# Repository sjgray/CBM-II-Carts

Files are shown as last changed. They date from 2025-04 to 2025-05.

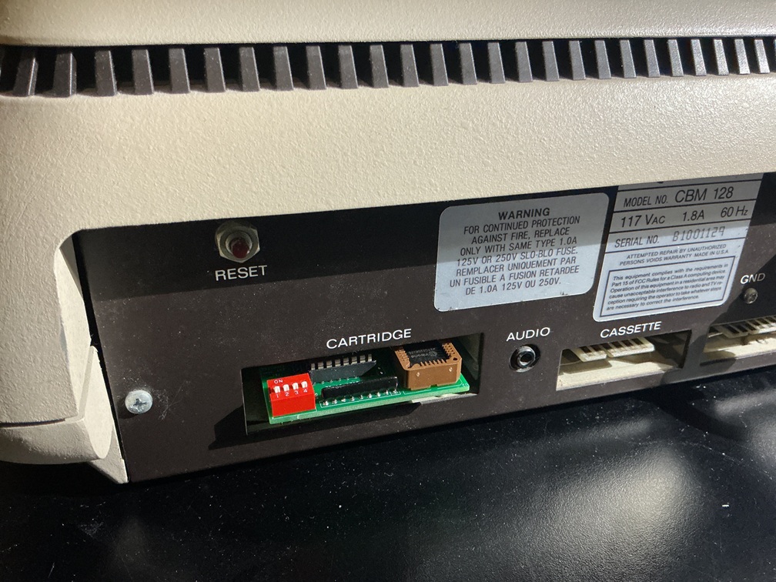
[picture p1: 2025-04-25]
ROMCart/_Pics/installed.jpg

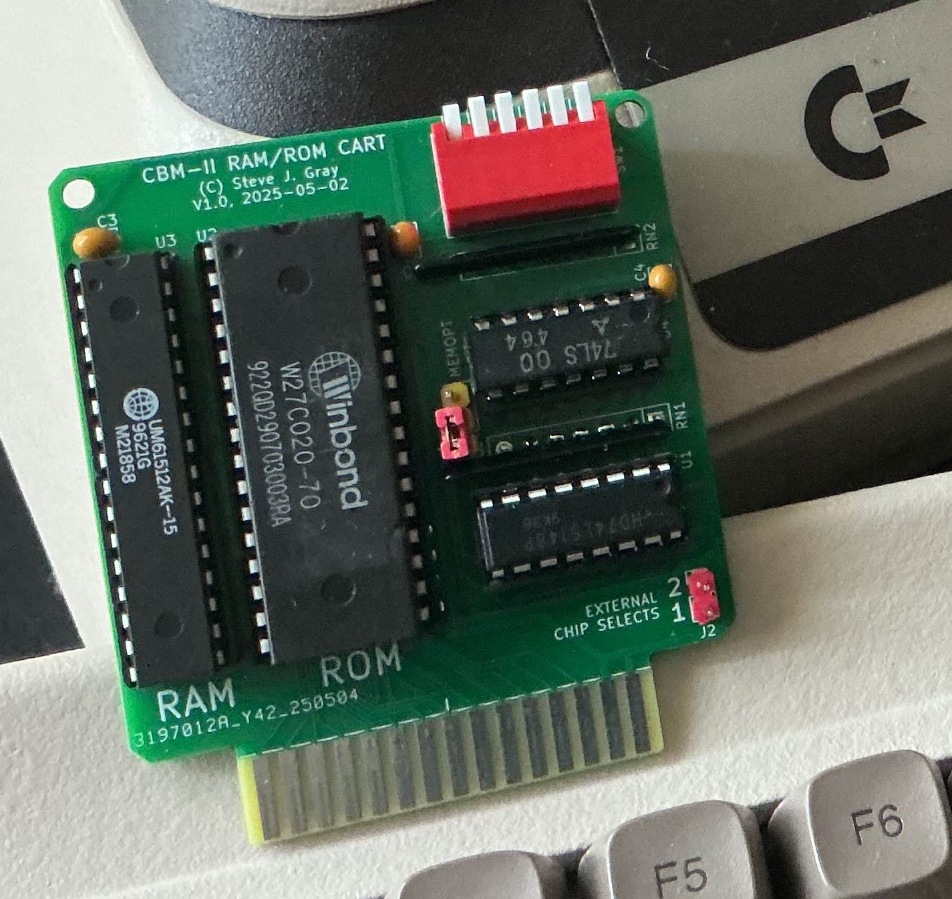
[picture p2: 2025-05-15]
RAMROMCart/pics/CBM-II-RAM-ROM-Cart.jpg

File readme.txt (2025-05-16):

CBM-II Cartridges - Steve J. Gray
=================

This repository will contain CBM-II cartridges of my own design plus (in the future)
clones of original cartridges.

Normal cartridges space is in BANK 15, with 3 decoded ranges:

* $2000-3FFF (8K)
* $4000-5FFF (8K)
* $6000-7FFF (8K)

There are also 2 additional areas that are decoded but not available on the cartridge port.
These can be used by connecting wires from the cartridge to pins on a PLA chip inside the computer.
The areas are:

* $1000-1FFF (4K) - B and P-series
* $C000-CFFF (4K) - Not available on P-series!

Directory   Ver  Date      Status    Description
---------   ---  ----      ------    -----------
ROMCart     1.0  20240412  Working   My 256K ROM-only cart. 8 sets of 32K ($2000-$7FFF, plus one definable)
RAM+ROMCart 1.0  20250502  Working   My 32K RAM/256K ROM cart. RAM: (24K+8K), ROM: 8 sets of 32K ($2000-$7FFF, plus one definable)
CartImages   -   20250425  -         Collections of 256K ROM cartridge sets

Webpage: cbmsteve.ca/cbm2cart/index.html

Steve

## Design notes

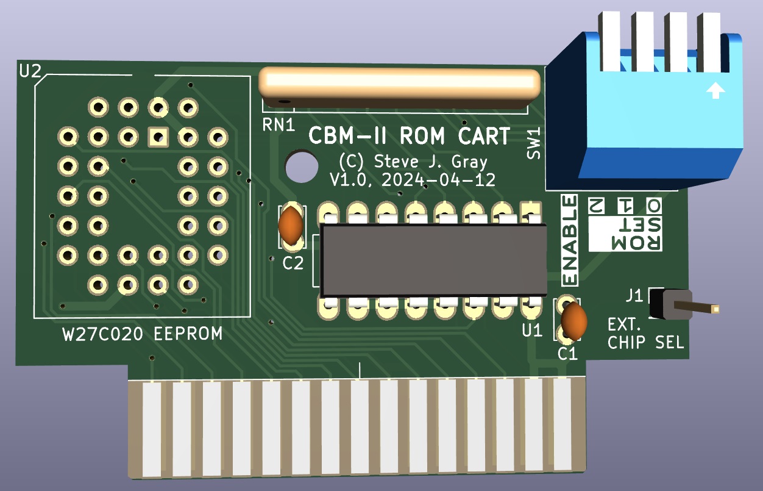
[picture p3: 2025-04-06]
ROMCart/_Pics/2024-04-12-Upgrade-256K.jpg

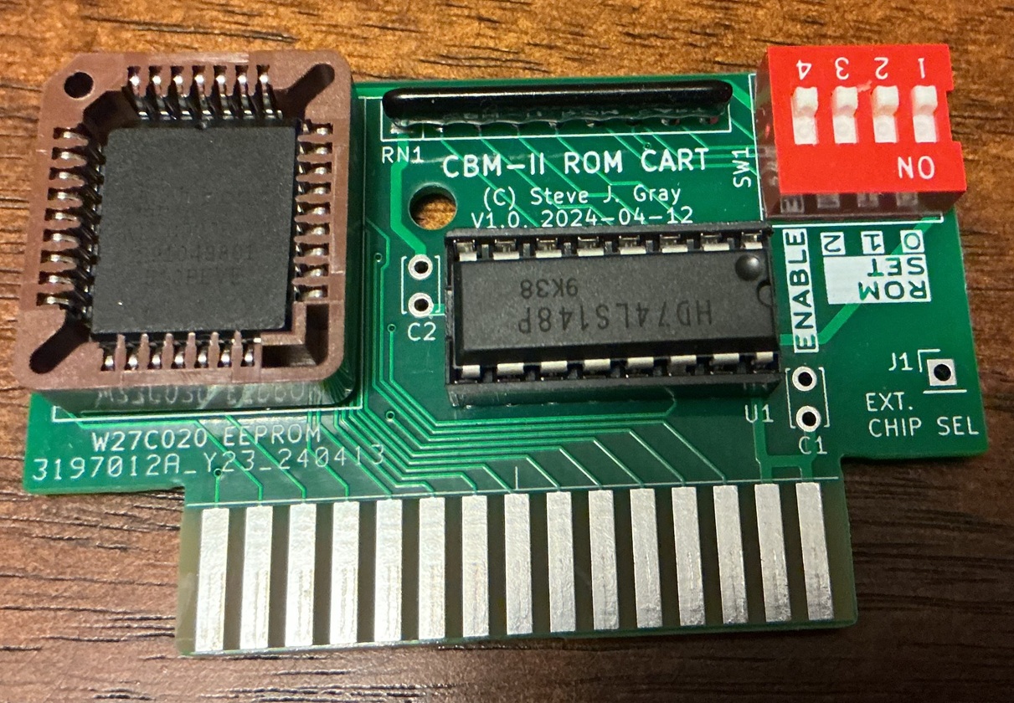
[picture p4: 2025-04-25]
ROMCart/_Pics/romcart.jpg

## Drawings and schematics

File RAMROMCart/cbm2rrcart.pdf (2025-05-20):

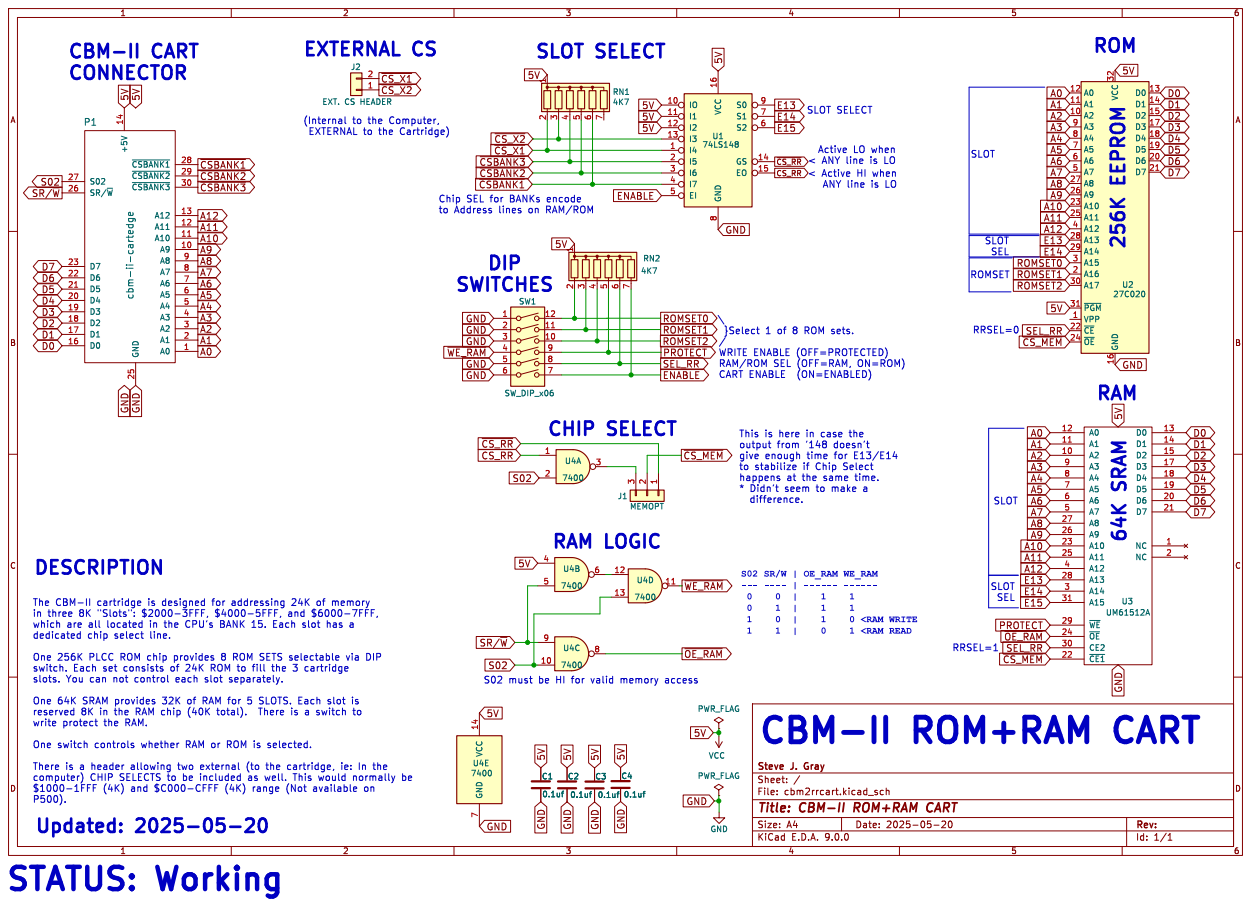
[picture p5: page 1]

Active LO when < ANY line is LO

CART ENABLE (ON=ENABLED) < Active HI when ANY line is LO

Chip SEL for BANKs encode
to Address lines on RAM/ROM

}Select 1 of 8 ROM sets.
/WRITE ENABLE (OFF=PROTECTED)

RAM/ROM SEL (OFF=RAM, ON=ROM)

output from '148 doesn't give enough time for E13/E14

happens at the same time. * Didn't seem to make a

One 64K SRAM provides 32K of RAM for 5 SLOTS. Each slot is

File: cbm2rrcart.kicad_sch Sheet: / Steve J. Gray

Id: 1/1 Title: CBM-II ROM+RAM CART

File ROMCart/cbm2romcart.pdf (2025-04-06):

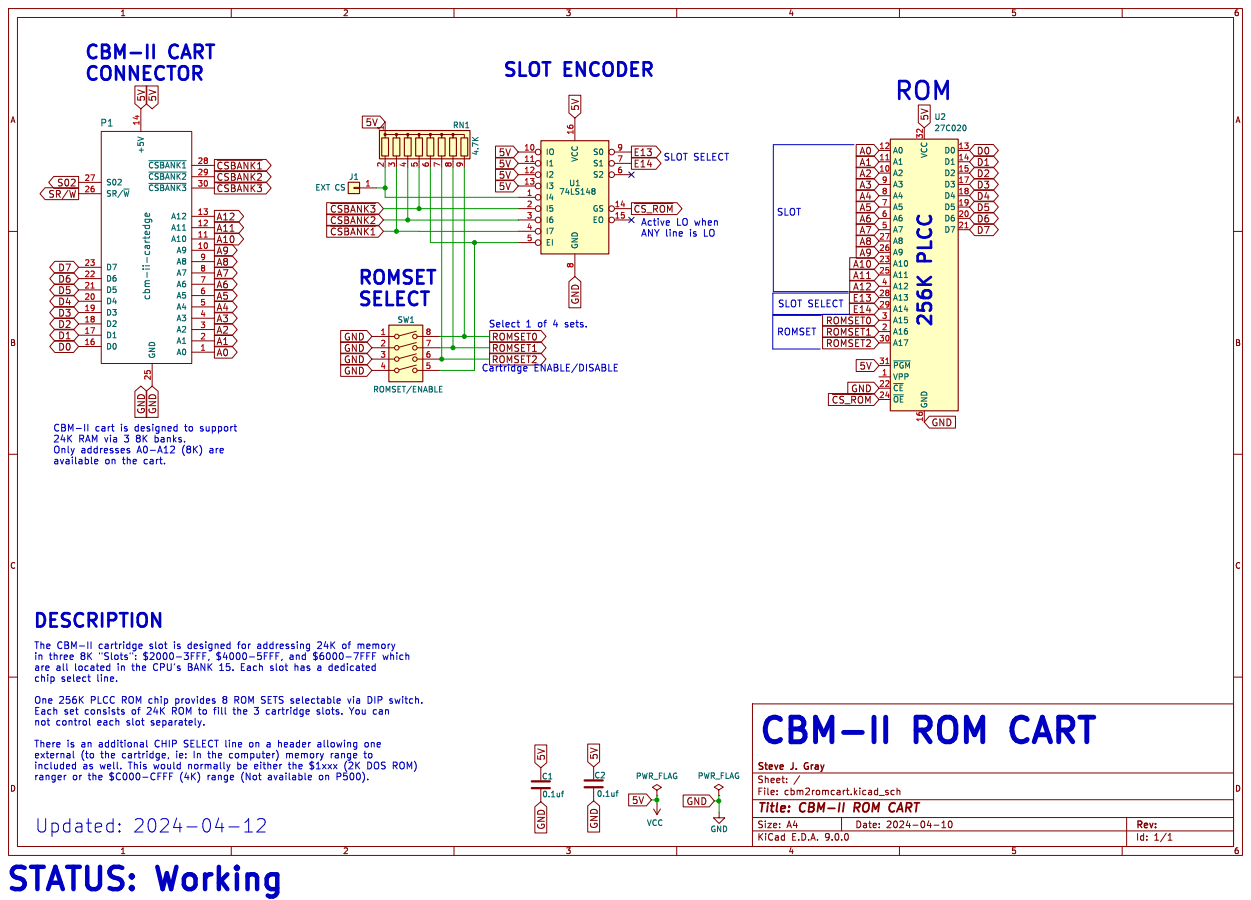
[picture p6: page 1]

9 RN1 4.7K A0 12 A1 11 A2 10 A3 9 A4 8 A5 7 A6 6 A7 5 A8 27 A9 26 A10 23 A11 25 A12 4 A13 28 A14 29 A15 3 A16 2 A17 30 ~{PGM} 31 VPP 1 ~{CE} 22 ~{OE} 24 VCC 32 GND 16 D0 13 D1 14 D2 15 D3 17 D4 18 D5 19 D6 20 D7 21 U2

are all located in the CPU's BANK 15. Each slot has a dedicated

Id: 1/1 Title: CBM-II ROM CART

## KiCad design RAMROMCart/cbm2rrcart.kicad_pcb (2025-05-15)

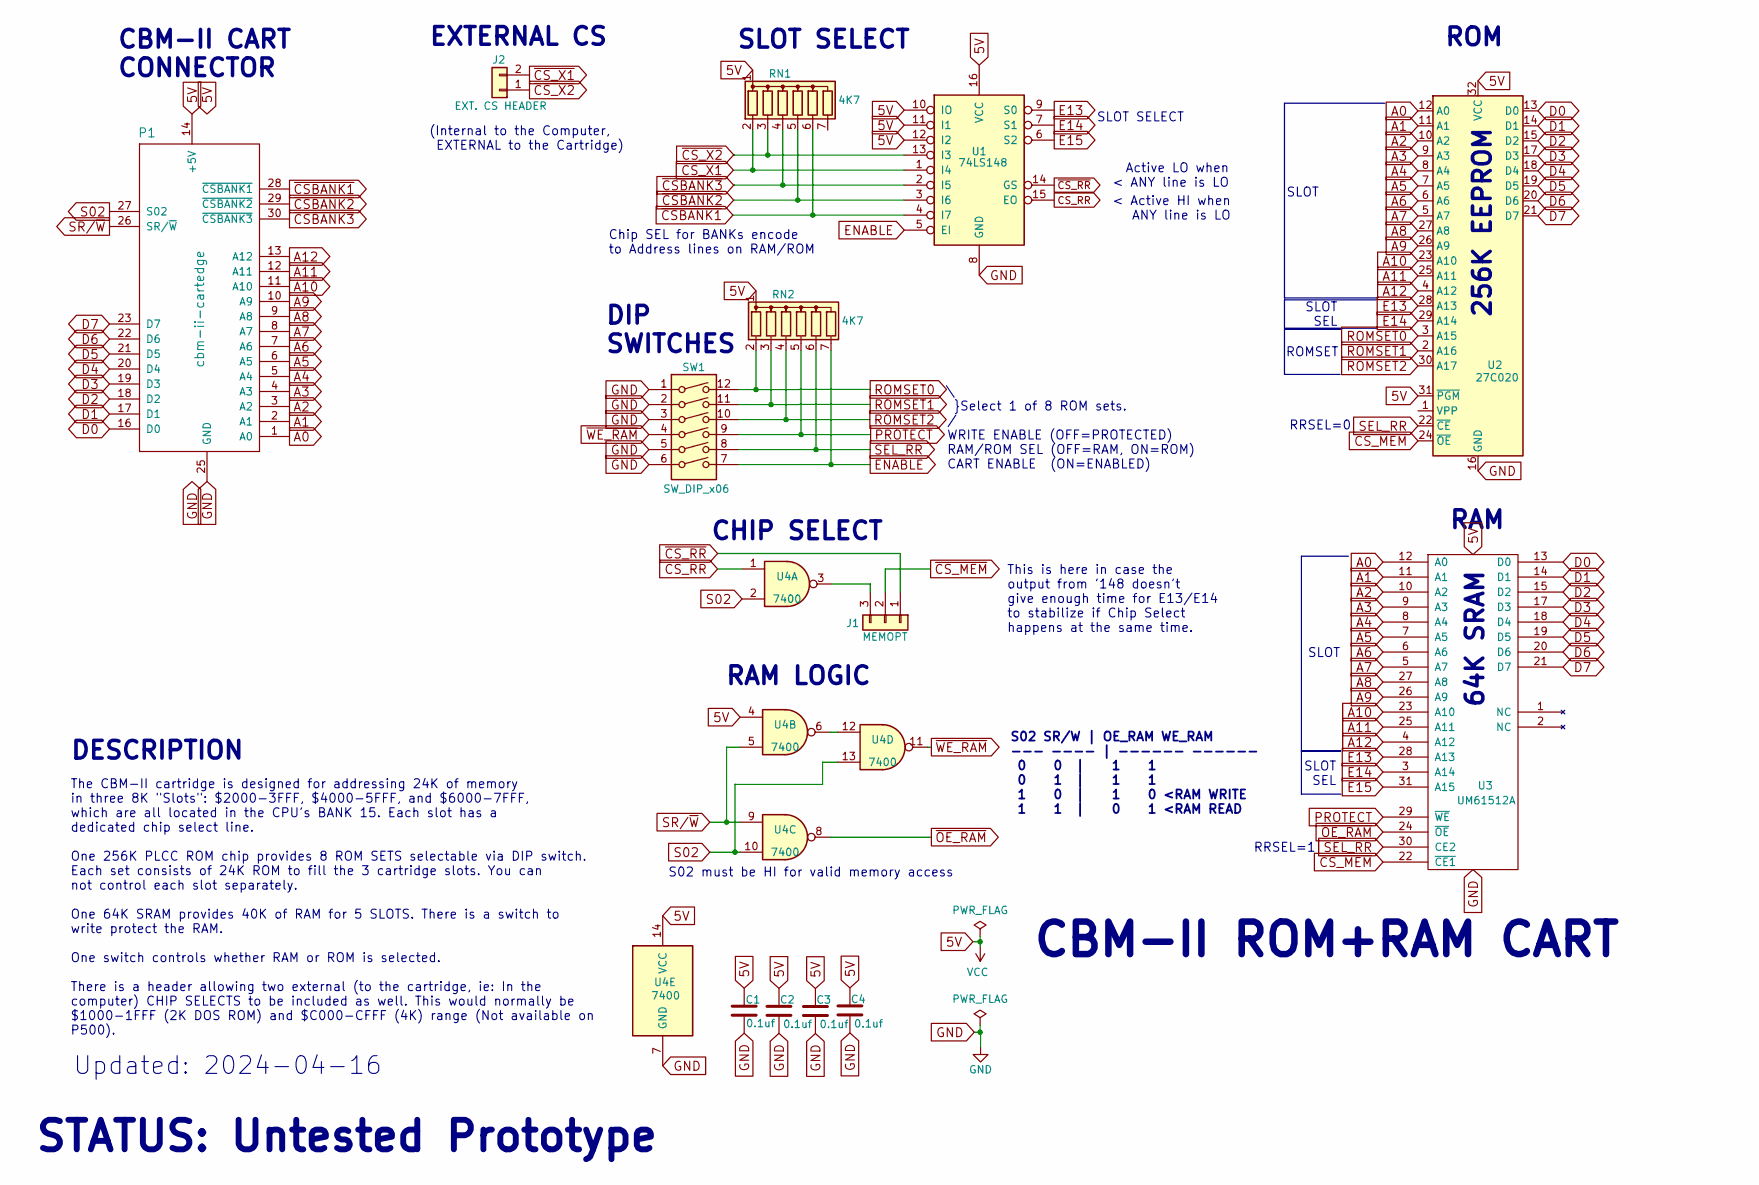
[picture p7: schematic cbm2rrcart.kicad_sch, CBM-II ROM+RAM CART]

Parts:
C1: 0.1uf; PinHeader_1x03_P2.54mm_Vertical_SMD_Pin1Right
C2, C3, C4: 0.1uf; C_Disc_D3.4mm_W2.1mm_P2.50mm
J1: MEMOPT; PinHeader_1x03_P2.54mm_Vertical
J2: EXT. CS HEADER; PinHeader_1x02_P2.54mm_Vertical
P1: cbm-ii-cartedge; CBM2-Cart-Edge
RN1, RN2: 4K7; R_Array_SIP7
SW1: SW_DIP_x06; SW_DIP_SPSTx06_Piano_10.8x16.8mm_W7.62mm_P2.54mm
U1: 74LS148; DIP-16_W7.62mm_LongPads
U2: 27C020; DIP-32_W15.24mm_LongPads
U3: UM61512A; DIP-32_W7.62mm
U4: 7400; DIP-14_W7.62mm_LongPads

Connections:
5V: C1.1, C2.1, C3.1, C4.1, P1.14 (+5V), P1.15 (+5V), RN1.1 (common), RN2.1 (common), U1.10 (IO), U1.11 (I1), U1.12 (I2), U1.16 (VCC), U2.31 (~PGM), U2.32 (VCC), U3.32 (VCC), U4.4, U4.14 (VCC)
A0: P1.1 (A0), U2.12 (A0), U3.12 (A0)
A1: P1.2 (A1), U2.11 (A1), U3.11 (A1)
A2: P1.3 (A2), U2.10 (A2), U3.10 (A2)
A3: P1.4 (A3), U2.9 (A3), U3.9 (A3)
A4: P1.5 (A4), U2.8 (A4), U3.8 (A4)
A5: P1.6 (A5), U2.7 (A5), U3.7 (A5)
A6: P1.7 (A6), U2.6 (A6), U3.6 (A6)
A7: P1.8 (A7), U2.5 (A7), U3.5 (A7)
A8: P1.9 (A8), U2.27 (A8), U3.27 (A8)
A9: P1.10 (A9), U2.26 (A9), U3.26 (A9)
A10: P1.11 (A10), U2.23 (A10), U3.23 (A10)
A11: P1.12 (A11), U2.25 (A11), U3.25 (A11)
A12: P1.13 (A12), U2.4 (A12), U3.4 (A12)
CS_RR: U1.15 (EO), U4.1
D0: P1.16 (D0), U2.13 (D0), U3.13 (D0)
D1: P1.17 (D1), U2.14 (D1), U3.14 (D1)
D2: P1.18 (D2), U2.15 (D2), U3.15 (D2)
D3: P1.19 (D3), U2.17 (D3), U3.17 (D3)
D4: P1.20 (D4), U2.18 (D4), U3.18 (D4)
D5: P1.21 (D5), U2.19 (D5), U3.19 (D5)
D6: P1.22 (D6), U2.20 (D6), U3.20 (D6)
D7: P1.23 (D7), U2.21 (D7), U3.21 (D7)
E13: U1.9 (S0), U2.28 (A13), U3.28 (A13)
E14: U1.7 (S1), U2.29 (A14), U3.3 (A14)
E15: U1.6 (S2), U3.31 (A15)
ENABLE: RN2.7 (R6), SW1.7, U1.5 (EI)
GND: C1.2, C2.2, C3.2, C4.2, P1.24 (GND), P1.25 (GND), SW1.1, SW1.2, SW1.3, SW1.5, SW1.6, U1.8 (GND), U2.16 (GND), U3.16 (GND), U4.7 (GND)
unnamed: J1.3, U4.3
unnamed: U4.6, U4.12
PROTECT: RN2.5 (R4), SW1.9, U3.29 (~WE)
ROMSET0: RN2.2 (R1), SW1.12, U2.3 (A15)
ROMSET1: RN2.3 (R2), SW1.11, U2.2 (A16)
ROMSET2: RN2.4 (R3), SW1.10, U2.30 (A17)
S02: P1.27 (S02), U4.2, U4.10, U4.13
SEL_RR: RN2.6 (R5), SW1.8, U2.22 (~CE), U3.30 (CE2)
SR/~W: P1.26 (SR/~W), U4.5, U4.9
~CSBANK1: P1.28 (~CSBANK1), RN1.6 (R5), U1.4 (I7)
~CSBANK2: P1.29 (~CSBANK2), RN1.5 (R4), U1.3 (I6)
~CSBANK3: P1.30 (~CSBANK3), RN1.4 (R3), U1.2 (I5)
~CS_MEM: J1.2, U2.24 (~OE), U3.22 (~CE1)
~CS_RR: J1.1, U1.14 (GS)
~CS_X1: J2.2, RN1.2 (R1), U1.1 (I4)
~CS_X2: J2.1, RN1.3 (R2), U1.13 (I3)
~OE_RAM: U3.24 (~OE), U4.8
~WE_RAM: SW1.4, U4.11

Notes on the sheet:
DESCRIPTION
CBM-II CART CONNECTOR
S02 must be HI for valid memory access
SLOT SELECT
SLOT SEL
RAM LOGIC
SLOT
ROM
The CBM-II cartridge is designed for addressing 24K of memory in three 8K "Slots": $2000-3FFF, $4000-5FFF, and $6000-7FFF, which are all located in the CPU's BANK 15. Each slot has a dedicated chip select line. One 256K PLCC ROM chip provides 8 ROM SETS selectable via DIP switch. Each set consists 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
RRSEL=0
Active LO when < ANY line is LO
DIP SWITCHES
Updated: 2024-04-16
64K SRAM
CBM-II ROM+RAM CART
RRSEL=1
This is here in case the output from '148 doesn't give enough time for E13/E14 to stabilize if Chip Select happens at the same time.
S02 SR/W | OE_RAM WE_RAM --- ---- | ------ ------ 0 0 | 1 1 0 1 | 1 1 1 0 | 1 0 <RAM WRITE 1 1 | 0 1 <RAM READ
ROMSET
256K EEPROM
STATUS: Untested Prototype
\ }Select 1 of 8 ROM sets. / WRITE ENABLE (OFF=PROTECTED) RAM/ROM SEL (OFF=RAM, ON=ROM) CART ENABLE (ON=ENABLED)
(Internal to the Computer, EXTERNAL to the Cartridge)
EXTERNAL CS
< Active HI when ANY line is LO
CHIP SELECT
RAM
Chip SEL for BANKs encode to Address lines on RAM/ROM

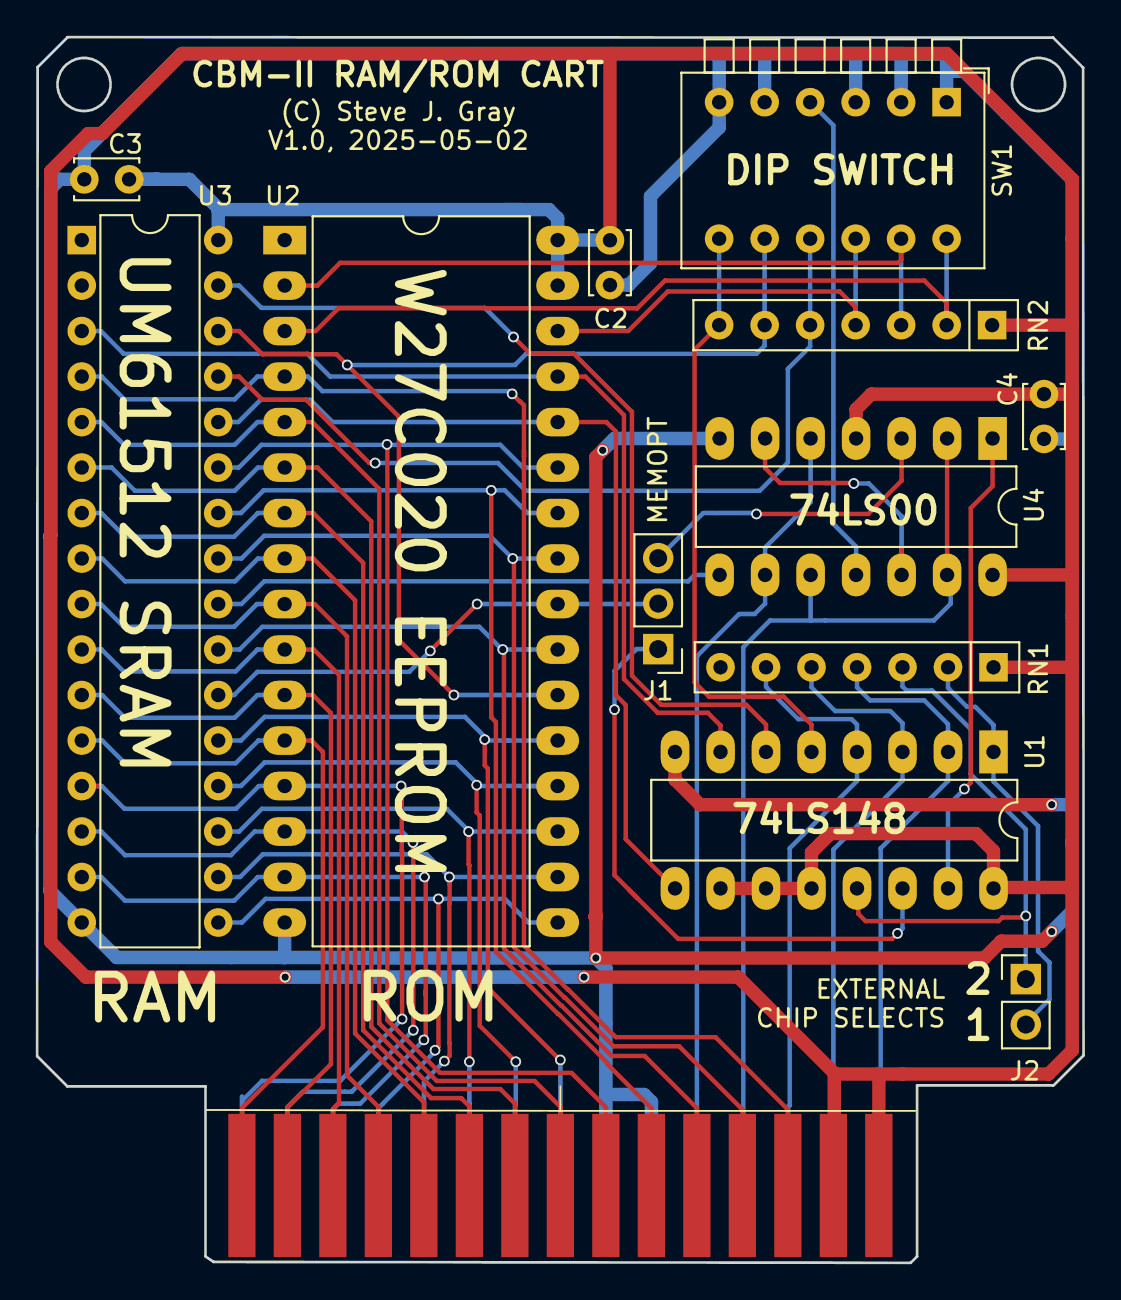
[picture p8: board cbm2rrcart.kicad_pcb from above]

Board: 2 copper layers, 58.4 x 68.4 mm, 13 parts (0 on the bottom side), 46 nets.

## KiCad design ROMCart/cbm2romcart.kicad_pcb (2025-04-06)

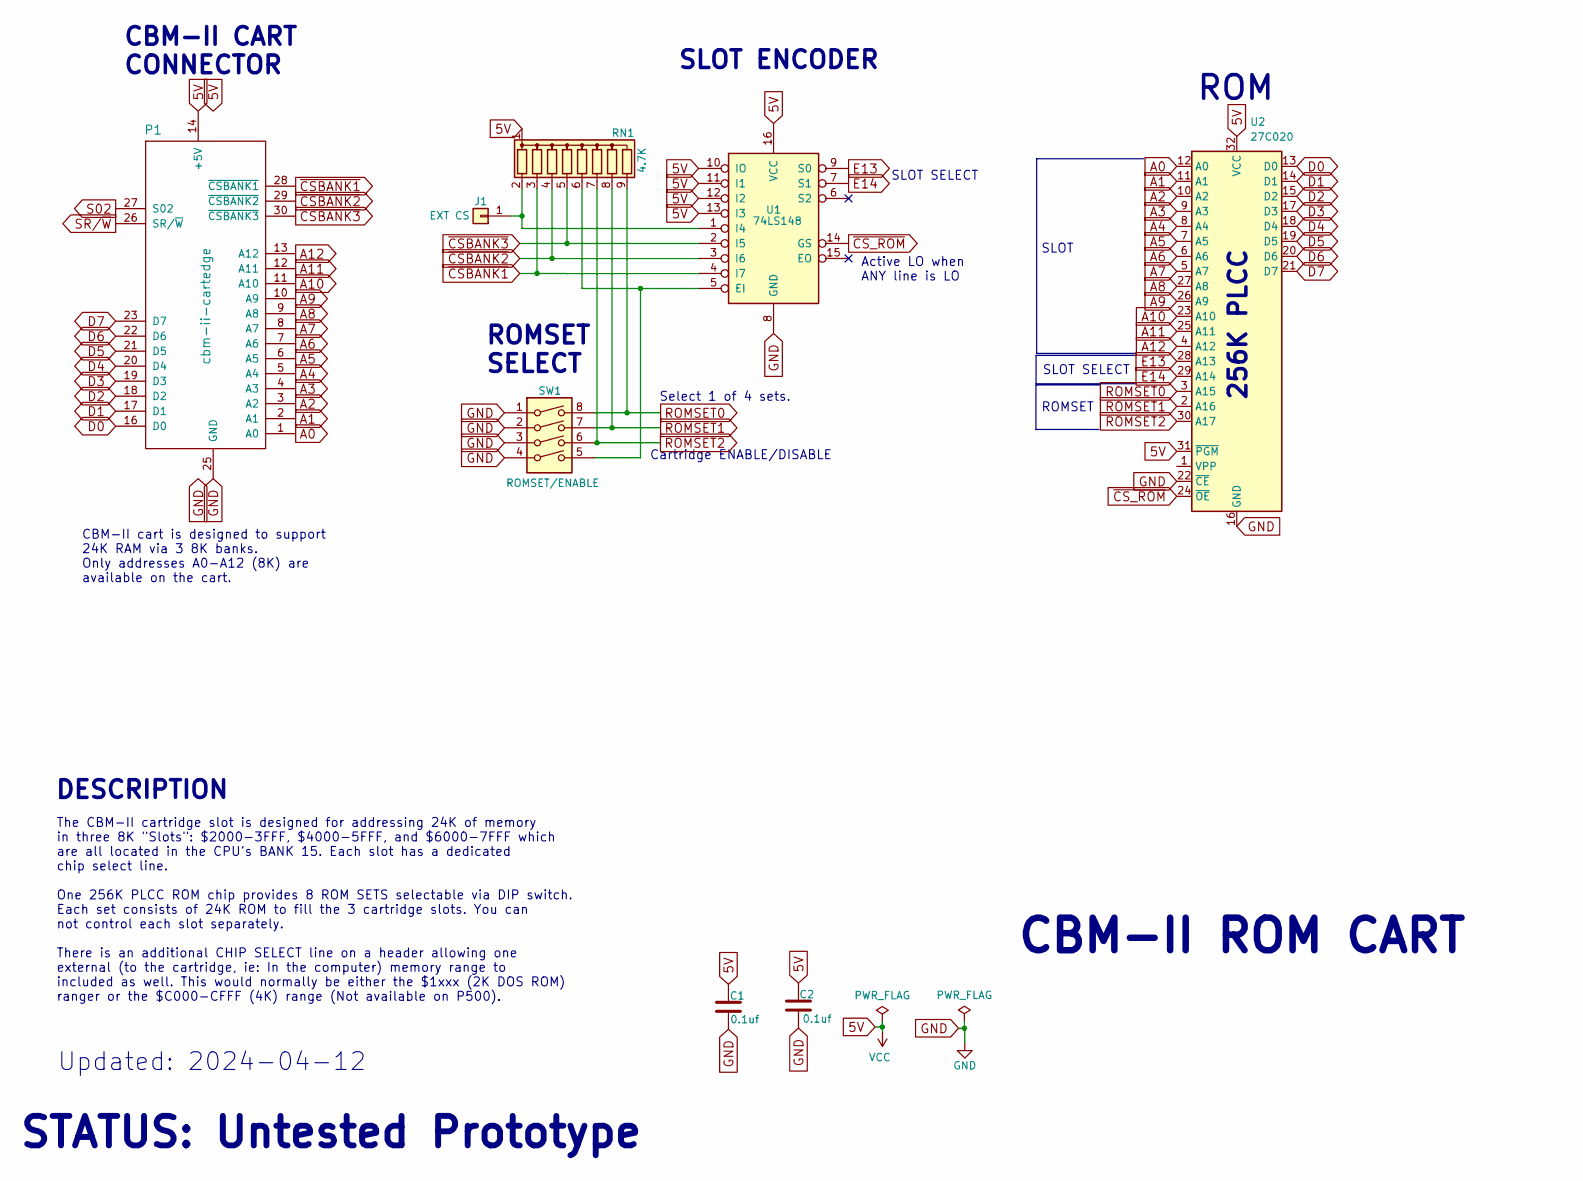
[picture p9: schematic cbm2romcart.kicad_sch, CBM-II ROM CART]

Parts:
C1, C2: 0.1uf; C_Disc_D3.4mm_W2.1mm_P2.50mm
J1: EXT CS; PinHeader_1x01_P2.54mm_Vertical
P1: cbm-ii-cartedge; CBM2-Cart-Edge
RN1: 4.7K; R_Array_SIP9
SW1: ROMSET/ENABLE; SW_DIP_SPSTx04_Piano_10.8x11.72mm_W7.62mm_P2.54mm
U1: 74LS148; DIP-16_W7.62mm_LongPads
U2: 27C020; PLCC-32_THT-Socket

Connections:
5V: C1.1, C2.1, P1.14 (+5V), P1.15 (+5V), RN1.1 (common), U1.10 (IO), U1.11 (I1), U1.12 (I2), U1.13 (I3), U1.16 (VCC), U2.31 (~PGM), U2.32 (VCC)
A0: P1.1 (A0), U2.12 (A0)
A1: P1.2 (A1), U2.11 (A1)
A2: P1.3 (A2), U2.10 (A2)
A3: P1.4 (A3), U2.9 (A3)
A4: P1.5 (A4), U2.8 (A4)
A5: P1.6 (A5), U2.7 (A5)
A6: P1.7 (A6), U2.6 (A6)
A7: P1.8 (A7), U2.5 (A7)
A8: P1.9 (A8), U2.27 (A8)
A9: P1.10 (A9), U2.26 (A9)
A10: P1.11 (A10), U2.23 (A10)
A11: P1.12 (A11), U2.25 (A11)
A12: P1.13 (A12), U2.4 (A12)
D0: P1.16 (D0), U2.13 (D0)
D1: P1.17 (D1), U2.14 (D1)
D2: P1.18 (D2), U2.15 (D2)
D3: P1.19 (D3), U2.17 (D3)
D4: P1.20 (D4), U2.18 (D4)
D5: P1.21 (D5), U2.19 (D5)
D6: P1.22 (D6), U2.20 (D6)
D7: P1.23 (D7), U2.21 (D7)
E13: U1.9 (S0), U2.28 (A13)
E14: U1.7 (S1), U2.29 (A14)
GND: C1.2, C2.2, P1.24 (GND), P1.25 (GND), SW1.1, SW1.2, SW1.3, SW1.4, U1.8 (GND), U2.16 (GND), U2.22 (~CE)
unnamed: J1.1, RN1.2 (R1), U1.1 (I4)
unnamed: RN1.6 (R5), SW1.5, U1.5 (EI)
ROMSET0: RN1.9 (R8), SW1.8, U2.3 (A15)
ROMSET1: RN1.8 (R7), SW1.7, U2.2 (A16)
ROMSET2: RN1.7 (R6), SW1.6, U2.30 (A17)
S02: P1.27 (S02)
SR/~W: P1.26 (SR/~W)
~CSBANK1: P1.28 (~CSBANK1), RN1.3 (R2), U1.4 (I7)
~CSBANK2: P1.29 (~CSBANK2), RN1.4 (R3), U1.3 (I6)
~CSBANK3: P1.30 (~CSBANK3), RN1.5 (R4), U1.2 (I5)
~CS_ROM: U1.14 (GS), U2.24 (~OE)

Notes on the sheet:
Select 1 of 4 sets.
DESCRIPTION
CBM-II CART CONNECTOR
ROM
SLOT ENCODER
SLOT SELECT
SLOT
The CBM-II cartridge slot is designed for addressing 24K of memory in three 8K "Slots": $2000-3FFF, $4000-5FFF, and $6000-7FFF which are all located in the CPU's BANK 15. Each slot has a dedicated chip select line. One 256K PLCC ROM chip provides 8 ROM SETS selectable via DIP switch. Each set consi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
CBM-II cart is designed to support 24K RAM via 3 8K banks. Only addresses A0-A12 (8K) are available on the cart.
Active LO when ANY line is LO
ROMSET SELECT
Updated: 2024-04-12
CBM-II ROM CART
Cartridge ENABLE/DISABLE
ROMSET
256K PLCC
STATUS: Untested Prototype

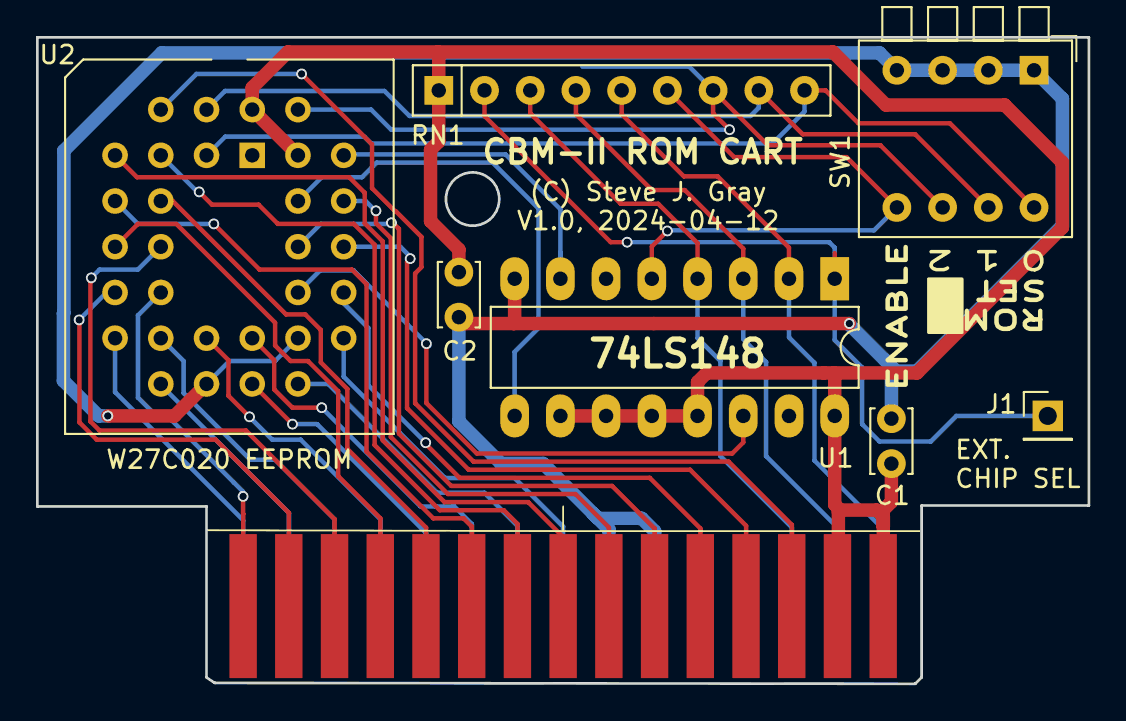
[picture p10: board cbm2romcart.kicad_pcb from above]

Board: 2 copper layers, 58.4 x 35.9 mm, 8 parts (0 on the bottom side), 34 nets.

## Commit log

2025-04-06 Initial
    Add my 256K ROM-only cartridge. Allows up to 8 sets of 32K. The regular cartridge slots $2000, $4000, and $6000 (8K each) become one 24K "set", plus you can add another 8K slot using the External Chi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
2025-04-06 Fix PDF
    The PDF schematic was incorrect. Fixed!
2025-05-15 Add RAM-ROM Cart V1.0
    The RAM/ROM cart adds 24K of RAM in the cartridge space plus up to 8K in the external space ($1000-1FFF or $C000-CFFF) or up to 8 selectable sets of 24K of ROM plus 4K of external space. The RAM can 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
    [cbm2rrcart-B_Cu.gbr, cbm2rrcart-B_Mask.gbr, cbm2rrcart-Edge_Cuts.gbr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]
